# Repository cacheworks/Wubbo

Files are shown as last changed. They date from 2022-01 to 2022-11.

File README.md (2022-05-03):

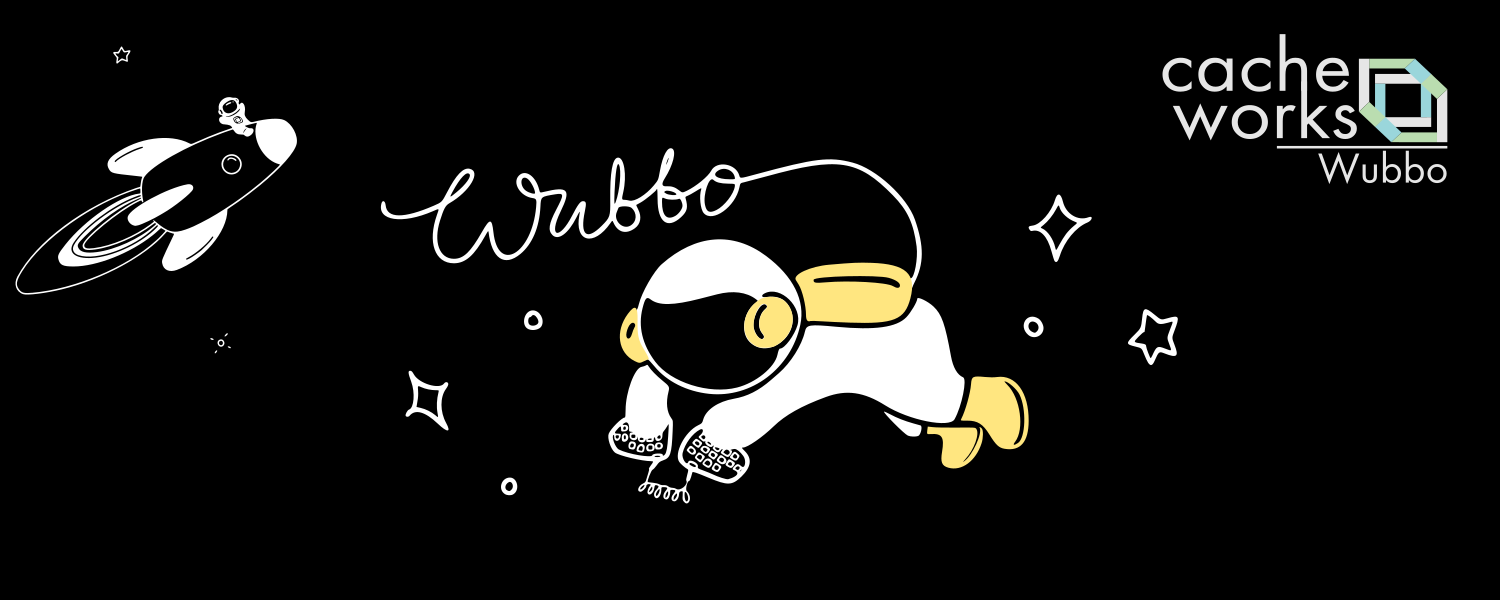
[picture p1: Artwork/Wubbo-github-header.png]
Wubbo header

A wireless 34 key keyboard with the top pinky keys moved to the 6th column.

### [Interactive Bill of materials](https://cacheworks.github.io/Wubbo/)
### [Example ZMK config repo](https://github.com/mveerd/wubbo-zmk-config)

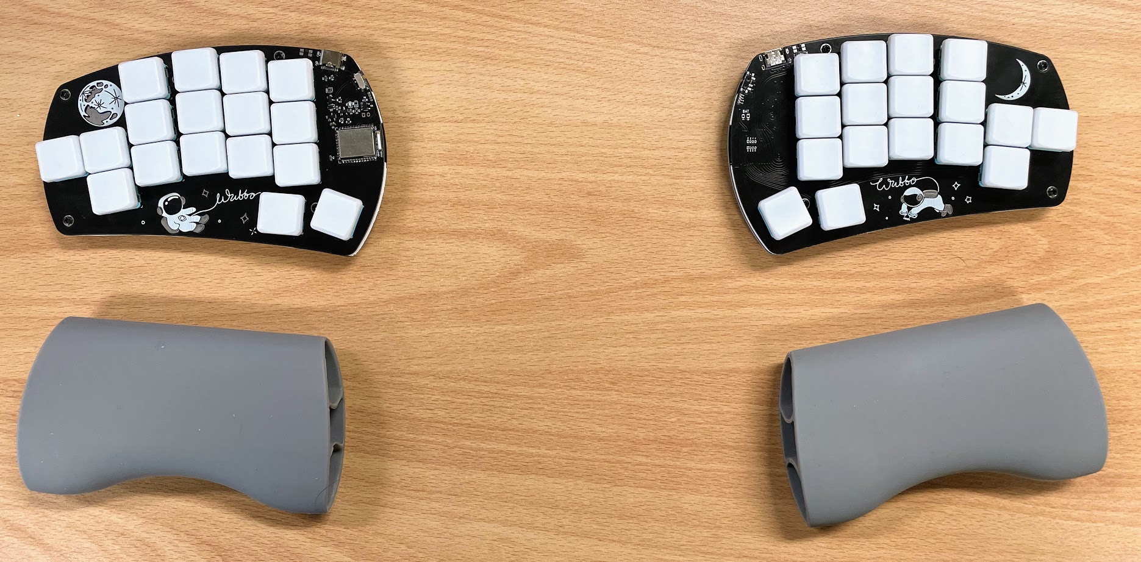
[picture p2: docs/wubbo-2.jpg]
Wubbo

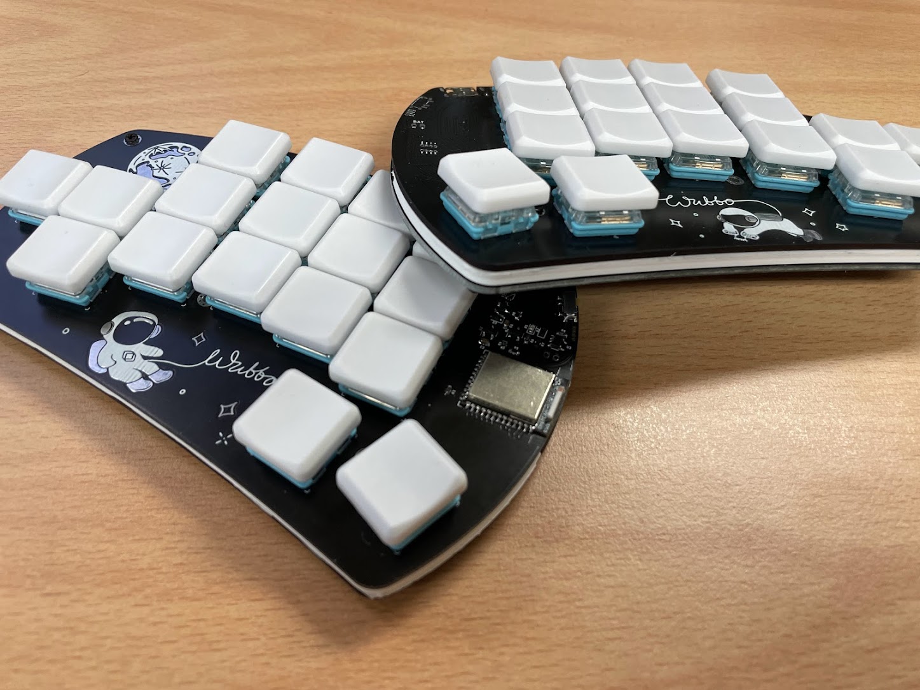
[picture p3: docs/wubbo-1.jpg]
Wubbo


---
__Why move the top pinky keys to the side?__  

 Moving my pinky to the side instead of upwards feels more natural and limits the movement and rotation of my hands on the board.  
This 'pinky cluster' is inspired by boards like [balbuzard](https://github.com/brow/balbuzard) and [osprette](https://github.com/smores56/osprette)

__Who did the silkscreen art?__  
  
All credits for the handdrawn art go to Perce at [madebyperce.com](https://madebyperce.com/)  🙇

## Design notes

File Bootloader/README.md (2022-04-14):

As defined in https://github.com/cacheworks/Adafruit_nRF52_Bootloader/tree/Wubbo/src/boards/wubbo

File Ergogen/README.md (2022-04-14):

This Ergogen config was only used for initial key / component placement and edge cut shape, further changes have been made in KiCad.

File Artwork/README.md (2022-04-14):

Full credits for all the hand-drawn art go to Perce [madebyperce.com](https://madebyperce.com/)  🙇

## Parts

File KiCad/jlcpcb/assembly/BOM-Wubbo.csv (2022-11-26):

Comment | Designator | Footprint | LCSC
SW_SPDT | SW_POW1 | SW_SPDT_PCM12 | C128955
1uF | C1,C2 | C_0603_1608Metric | C15849
4.7n | C3 | C_0805_2012Metric | C1744
AO3407 | Q1,Q2 | SOT-23 | C181093
D_Schottky | D3 | D_SOD-323 | C191023
1K | R6,R7 | R_0603_1608Metric | C21190
1M | R10 | R_0603_1608Metric | C22935
2M | R5,R9 | R_0603_1608Metric | C22976
5.1K | R1,R2 | R_0603_1608Metric | C23186
100K | R3 | R_0603_1608Metric | C25803
10K | R8 | R_0603_1608Metric | C25804
USBLC6-2P6 | ESD1 | SOT-666 | C2827693
LTC4054ES5-4.2 | U3 | TSOT-23-5 | C32574
806/820k | R4 | R_0603_1608Metric | C53198
XC6206P LDO | U2 | SOT-23 | C5446

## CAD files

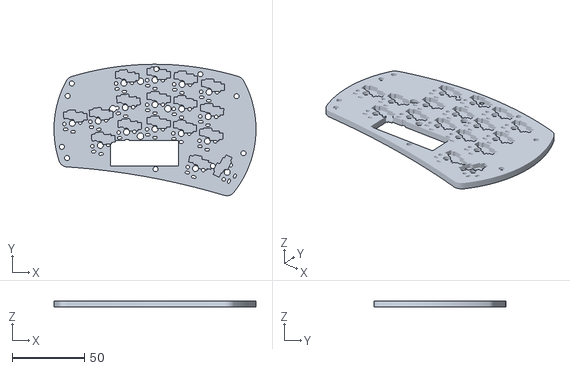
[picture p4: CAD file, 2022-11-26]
3D Print/wubmeat_v1 (1).stl
140.0 x 91.2 x 4.00

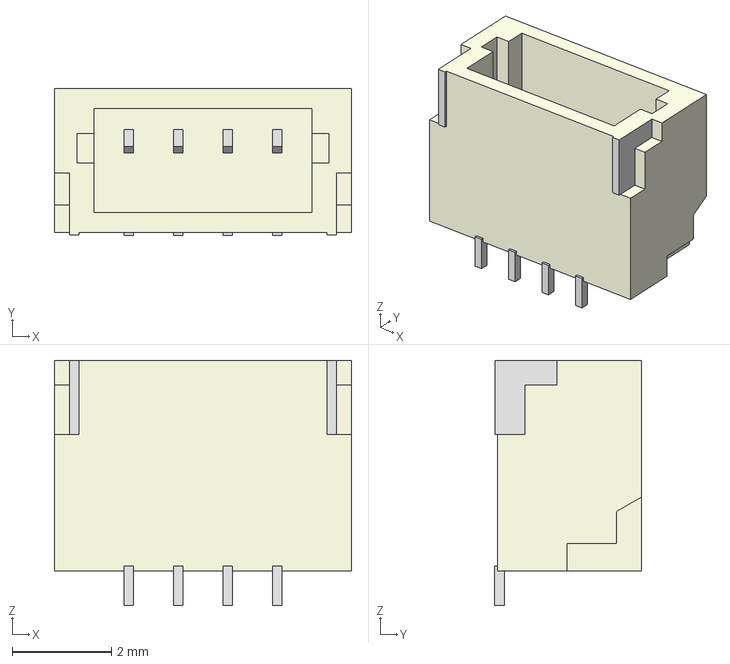
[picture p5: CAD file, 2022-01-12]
KiCad/3d/CON_SM04B-SRSS-TB.step
6.00 x 2.96 x 4.95 mm

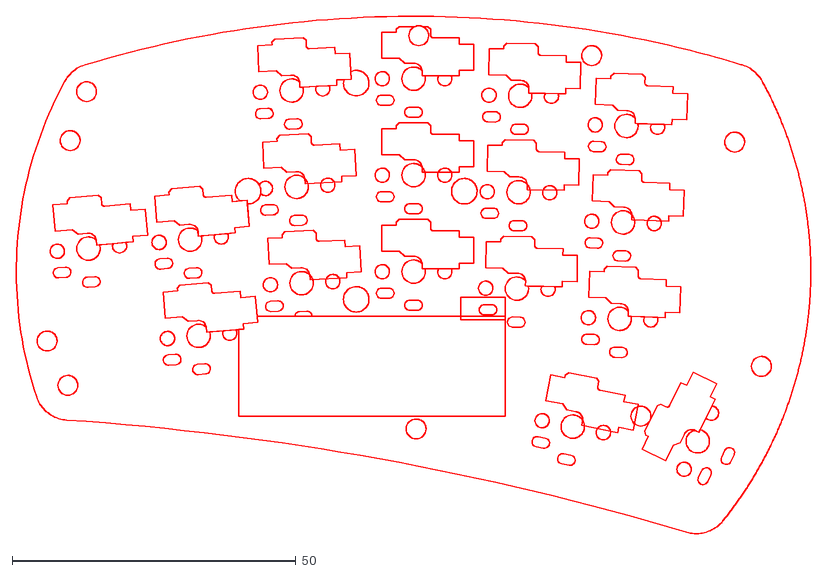
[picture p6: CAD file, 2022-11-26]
KiCad/svg/back/back.dxf
140.0 x 91.2

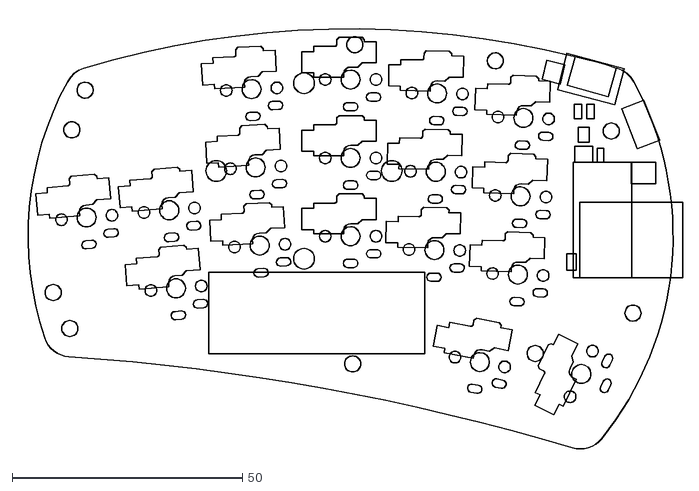
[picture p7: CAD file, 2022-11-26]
KiCad/svg/front/front.dxf
144.6 x 94.4

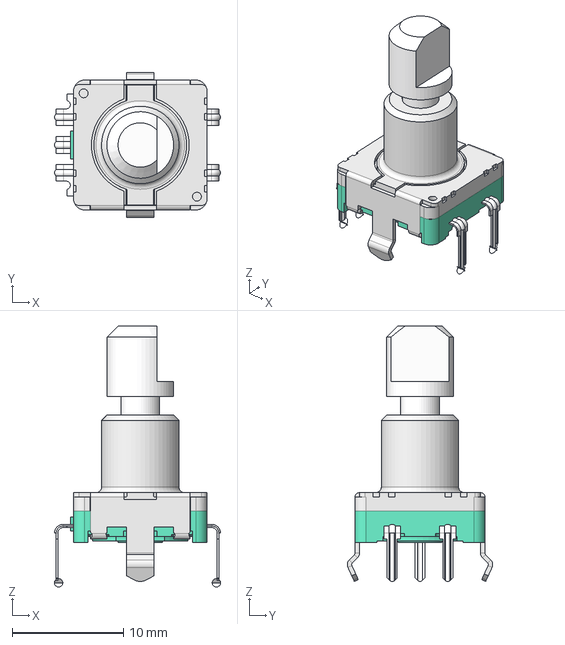
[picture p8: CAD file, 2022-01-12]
KiCad/3d/ROT_EC11N.step
14.9 x 13.1 x 23.5 mm

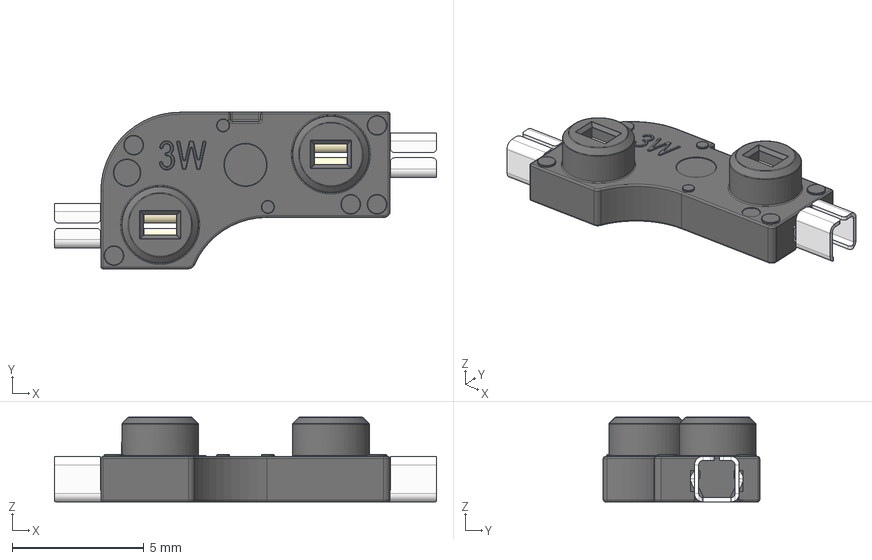
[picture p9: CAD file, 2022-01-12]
KiCad/3d/SW_Hotswap_Kailh.stp
14.5 x 5.95 x 3.22 mm

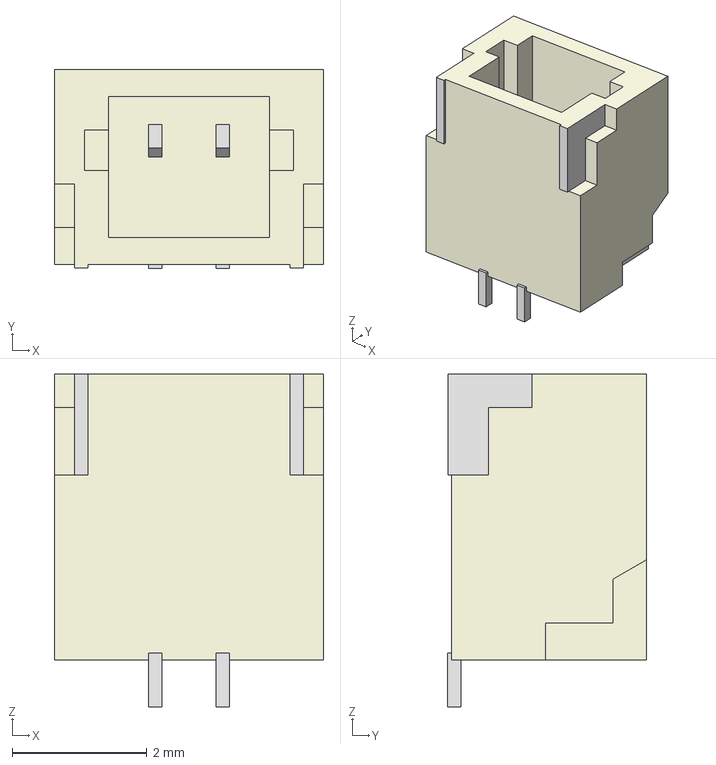
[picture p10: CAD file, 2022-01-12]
KiCad/3d/CON_SM02B-SRSS-TB.step
4.00 x 2.96 x 4.95 mm

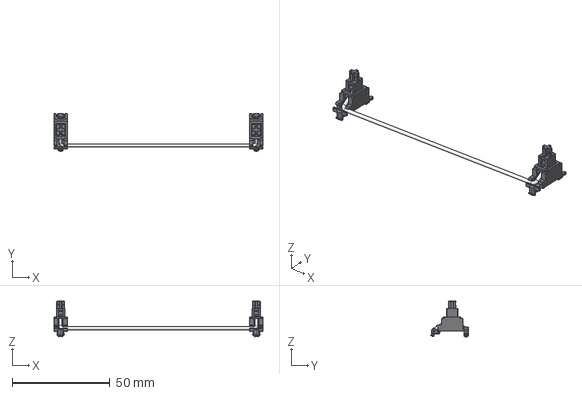
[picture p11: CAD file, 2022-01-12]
KiCad/3d/Stabilizer_Cherry_MX_6_25u.stp
106.8 x 19.2 x 18.3 mm

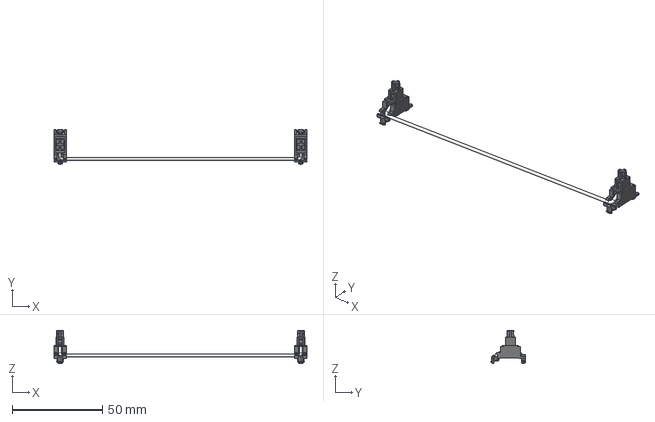
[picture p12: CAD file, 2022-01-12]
KiCad/3d/Stabilizer_Cherry_MX_8u.stp
140.1 x 19.2 x 18.3 mm

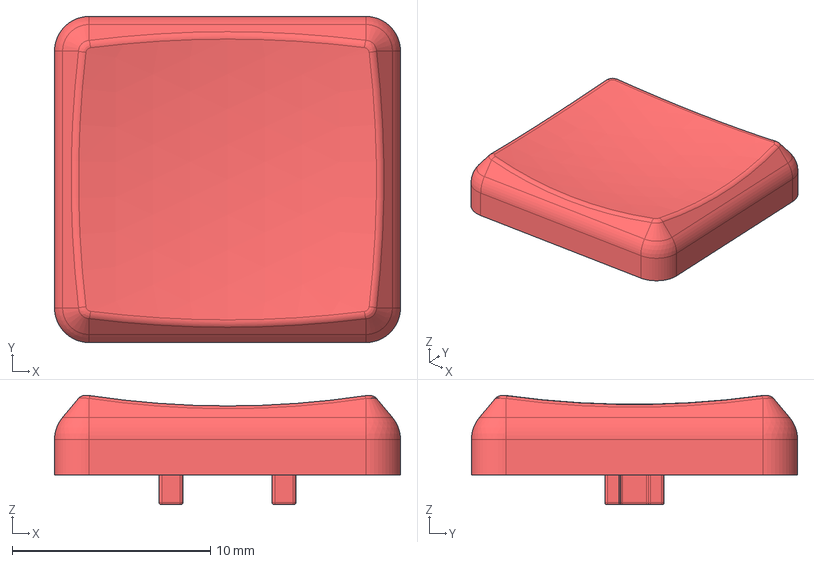
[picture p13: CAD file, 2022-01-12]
KiCad/3d/MBK_Keycap_-_1u.step
17.4 x 16.4 x 5.52 mm

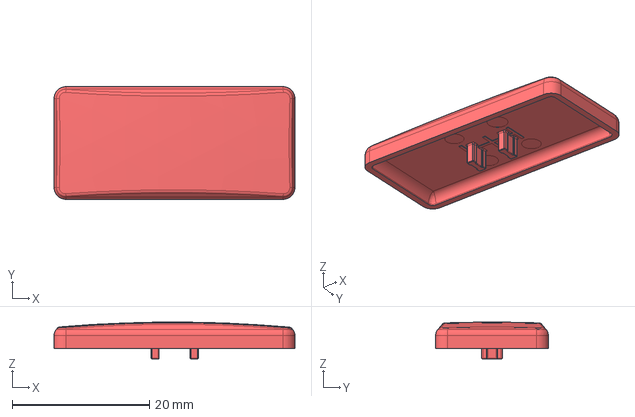
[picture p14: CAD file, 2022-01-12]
KiCad/3d/MBK_Keycap_-_2u.step
35.2 x 16.4 x 5.38 mm

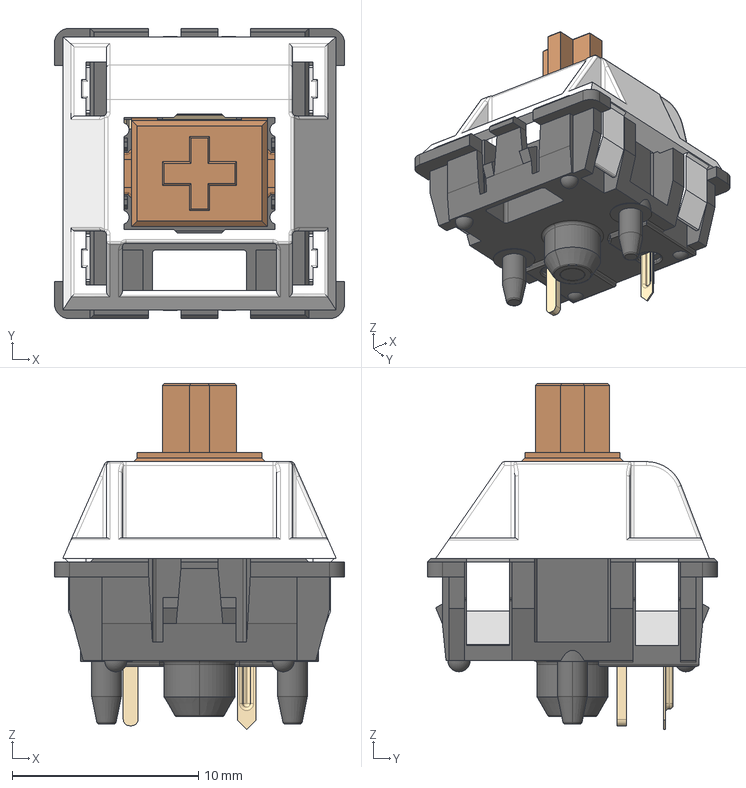
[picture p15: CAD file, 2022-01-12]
KiCad/3d/SW_Cherry_MX_PCB.stp
15.6 x 15.6 x 18.6 mm

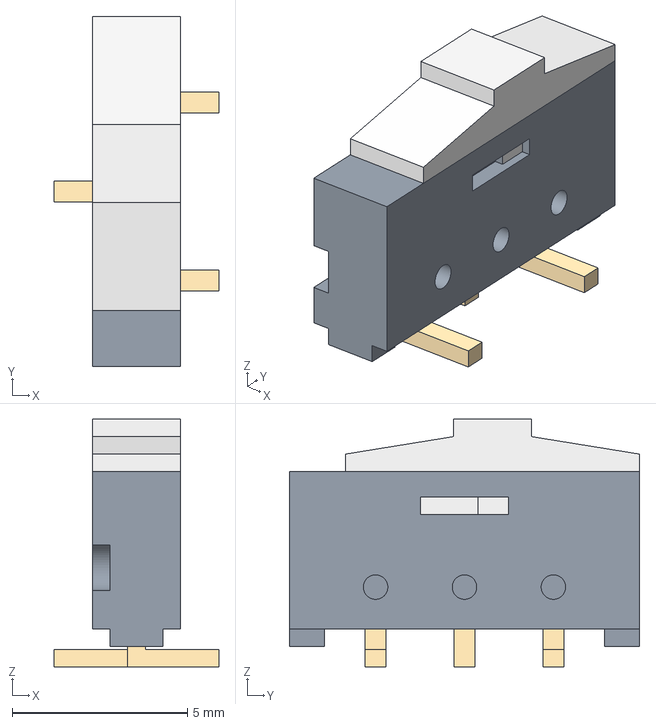
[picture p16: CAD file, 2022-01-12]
KiCad/3d/Switch_ESP3020.step
4.70 x 10.0 x 7.08 mm

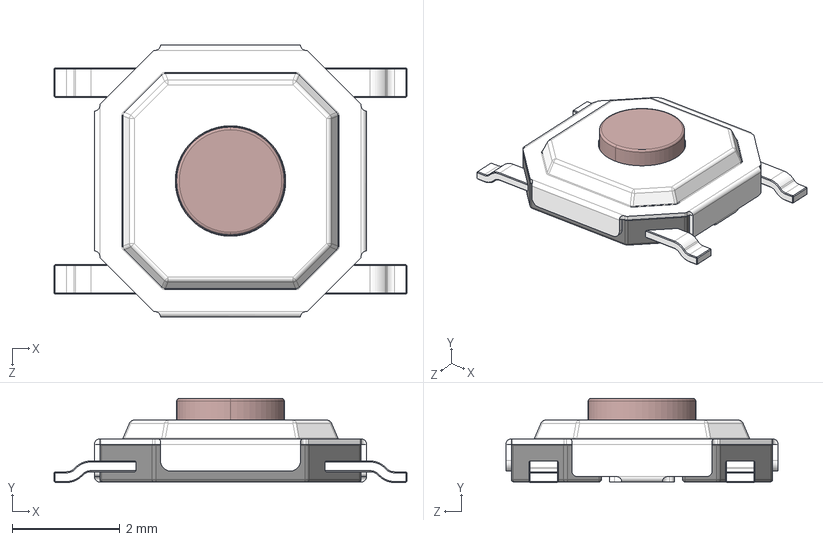
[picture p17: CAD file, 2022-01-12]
KiCad/3d/Switch_SKQG.step
6.55 x 1.56 x 5.05 mm
bottom part_ﾄｬﾈﾏｨｨ_
bottom pin_ﾄｬﾈﾏｨｨ_
top shield_ﾄｬﾈﾏｨｨ_
copper button_ﾄｬﾈﾏｨｨ_
shrapnel_默认è_

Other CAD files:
3D Print/frontmeat_v4.stl
KiCad/3d/HRO TYPE-C-31-M-12.step
KiCad/3d/USB-C-C168688.step
KiCad/3d/PG1350-socket.STEP
3D Print/wubmeat-back.f3d
3D Print/wubmeat-front.f3d
KiCad/3d/CON_Kailh_HS.step
KiCad/3d/CON_SM05B-SRSS-TB.step
KiCad/3d/CON_SM06B-SRSS-TB.step
KiCad/3d/CON_SM08B-SRSS-TB.step
KiCad/3d/CON_TYPE-C-31-M-12.step
KiCad/3d/Fuse_1206.step
KiCad/3d/LED_SK6812MINI-E.step
KiCad/3d/LED_WS2812B-MINI.step
KiCad/3d/MBK_1u.step
KiCad/3d/MBK_Keycap_-_1.5u.step
KiCad/3d/MBK_Keycap_-_1u_Homing.step
KiCad/3d/ROT_EC11E.step
KiCad/3d/SW_Cherry_MX_Plate.stp
KiCad/3d/SW_Kailh_Choc_V1.stp
KiCad/3d/Stabilizer_Cherry_MX_2u.stp
KiCad/3d/Stabilizer_Cherry_MX_3u.stp
KiCad/3d/Stabilizer_Cherry_MX_6u.stp
KiCad/3d/Stabilizer_Cherry_MX_7u.stp

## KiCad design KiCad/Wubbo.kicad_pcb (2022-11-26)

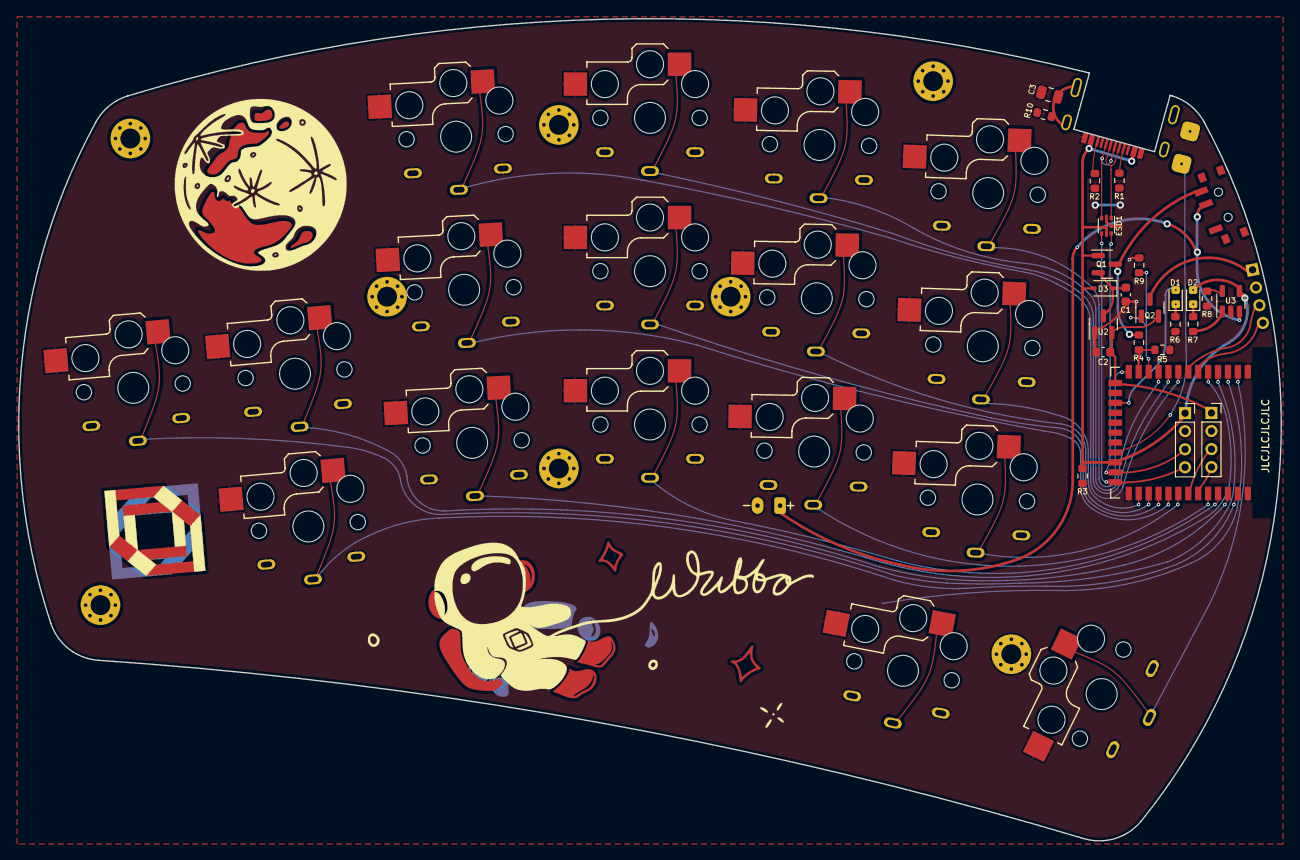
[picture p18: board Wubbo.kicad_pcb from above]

Board: 2 copper layers, 140.0 x 91.2 mm, 53 parts (1 on the bottom side), 43 nets.

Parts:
C1, C2: 1uF; C_0603_1608Metric
C3: 4.7n; C_0805_2012Metric
D1: Blue LED; LED_0603_1608Metric_shinethrough
D2: Red LED; LED_0603_1608Metric
D3: D_Schottky; D_SOD-323
ESD1: USBLC6-2P6; SOT-666
GR1, GR2: 9b7f651c-c6a4-4f53-b457-ec411c8fc700
GR3: frontright-2
GR4: frontleft-2
GR5: frontright-1
GR6: frontleft-1
J1: USB_C_Receptacle; USB-C-12-Pin-MidMount
J2: SWD; PinSocket_1x04_P2.00mm_Vertical
J3: USB; PinSocket_1x04_P2.00mm_Vertical
J4: JST-BATT; JST_PH_S2B-PH-K_1x02_P2.00mm_Horizontal
J5: USB; PinHeader_1x04_P2.00mm_Vertical
Q1, Q2: AO3407; SOT-23
R1, R2: 5.1K; R_0603_1608Metric
R3: 100K; R_0603_1608Metric
R4: 806/820k; R_0603_1608Metric
R5, R9: 2M; R_0603_1608Metric
R6, R7: 1K; R_0603_1608Metric
R8: 10K; R_0603_1608Metric
R10: 1M; R_0603_1608Metric
R_TACT1: SW_Push; 3-4-2_micro_tact_switch
SW1, SW2, SW3, SW4, SW5, SW6, SW7, SW8, SW9, SW10, SW11, SW12, SW13, SW14, SW15, SW16, SW17: Choc; combined-choc-reversible
SW_POW1: SW_SPDT; SW_SPDT_PCM12
TENT1: Tenting Puck; Tenting_Puck
U1: nRF52840_holyiot_18010
U2: XC6206P LDO; SOT-23
U3: LTC4054ES5-4.2; TSOT-23-5

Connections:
+3V3: C2.1, J2.1, Q2.2 (S), U1.14 (VDD_nRF), U2.2 (VO)
+BATT: J4.1, SW_POW1.2 (B), U3.3 (BAT)
/BAT+_SWITCHED: Q1.3 (D), R4.1, SW_POW1.3 (C)
/Net-(U3-PROG): R8.2, U3.5 (PROG)
/V-IN: C1.1, D3.1 (K), Q1.2 (S), U2.3 (VI)
BLUE_LED: D1.2 (A), U1.16 (P1.09)
D+: ESD1.4 (I/O2), J3.4, U1.24 (D+)
D-: ESD1.6 (I/O1), J3.3, U1.23 (D-)
EXT_VCC: J5.1, Q2.3 (D)
Earth: C3.2, J1.S1 (SHIELD), R10.2
GND: C1.2, C2.2, C3.1, ESD1.2 (GND), J1.A1 (GND), J2.2, J3.2, J4.2, J5.2, R1.2, R2.2, R3.2, R5.2, R6.2, R8.1, R9.2, R10.1, R_TACT1.2, SW1.2, SW2.2, SW3.2, SW4.2, SW5.2, SW6.2, SW7.2, SW8.2, SW9.2, SW10.2, SW11.2, SW12.2, SW13.2, SW14.2, SW15.2, SW16.2, SW17.2, U1.1 (GND), U1.25 (GND), U1.37 (GND), U2.1 (GND), U3.2 (GND)
unnamed: D1.1 (K), R6.1
unnamed: D2.1 (K), R7.1
unnamed: J1.A5 (CC1), R1.1
unnamed: J1.B5 (CC2), R2.1
unnamed: R7.2, U3.1 (~CHRG)
P0.02: J5.3, U1.7 (P0.02)
P0.03: J5.4, U1.6 (P0.03)
RESET: R_TACT1.1, U1.21 (P0.18/RESET)
SW1: SW1.1, U1.4 (P1.13)
SW2: SW2.1, U1.8 (P0.28)
SW3: SW3.1, U1.9 (P0.29)
SW4: SW4.1, U1.10 (P0.30)
SW5: SW5.1, U1.13 (P0.05)
SW6: SW6.1, U1.35 (P0.09)
SW7: SW7.1, U1.29 (P1.01)
SW8: SW8.1, U1.28 (P1.03)
SW9: SW9.1, U1.27 (P1.00)
SW10: SW10.1, U1.26 (P0.22)
SW11: SW11.1, U1.36 (P0.10)
SW12: SW12.1, U1.5 (P1.15)
SW13: SW13.1, U1.34 (P1.06)
SW14: SW14.1, U1.33 (P1.04)
SW15: SW15.1, U1.30 (P1.02)
SW16: SW16.1, U1.3 (P1.10)
SW17: SW17.1, U1.2 (P1.11)
SWDCLK: J2.3, U1.31 (SWDCLK)
SWDIO: J2.4, U1.32 (SWDIO)
USBD+: ESD1.3 (I/O2), J1.A6 (D+), J1.B6 (D+)
USBD-: ESD1.1 (I/O1), J1.A7 (D-), J1.B7 (D-)
VBUS: D2.2 (A), D3.2 (A), ESD1.5 (VBUS), J1.A4 (VBUS), J3.1, Q1.1 (G), R3.1, U1.22 (VBUS), U3.4 (VCC)
VCC_CONTROL: Q2.1 (G), R9.1, U1.11 (P0.31)
VSENSE: R4.2, R5.1, U1.12 (P0.04)

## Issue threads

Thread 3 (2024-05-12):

Symbol library missing?

iosonofabio, 2024-05-12:
hi there and thanks for sharing your awesome design! I really like it!

I'd like to open and edit the design in kicad, but it does not seem to be able to find the schematic library for the keyboard parts. Could it be that it's missing from the repo?

Thank you for your time!

MvEerd, 2024-05-13:
Hey, thanks for your interest, much appreciated!

I've just tried downloading the repo as zip and opened Wubbo.kicad_pro (in KiCad 8.0) and was able to open Wubbo.kicad_pcb and Wubbo.kicad_sch with seemingly no errors

Where are you getting the error and what does it say exactly? If it points to a specific library I'm happy to see if I have it locally andadd it to the repo for you!

iosonofabio, 2024-05-14:
Thank you for the quick reply!

I must be doing something wrong. The PCB does load but when I click on "Update PCB from Schematic" it throws a bunch of errors like this:

```
Cannot update SW15 (footprint 'kiboard_cache:PG13500-reversible' not found).
```

(17 errors in total, one per key I guess).

I tried to import the footprint from the same folder but still get the error.

If you could give me a tip in the right direction I'd really appreciate, apologies beforehand if it's a beginner mistake.

MvEerd, 2024-05-14:
No worries!

Unchecking 'Replace footprints with those specified in the schematic' in the Update PCB from Schematic would get rid of the 17 errors you are seeing for the keys.
I thought there should be no need to Update the PCB from Schematic since when I open the PCB and the schematic side by side it already highlights the components I click in the schematic in the PCB view so it already seems up to date.

It would be good to add the footprint to the repository though so I just re-extracted it from the PCB and uploaded the kiboard_cache library here [kiboard_cache.pretty.zip](https://github.com/cacheworks/Wubbo/files/15303986/kiboard_cache.pretty.zip)

By importing this library into your footprint editor, relaunching the PCB editor and trying to Update the PCB from Schematic again it should get rid of the error.
Another way is to import the footprint to any of your own libraries and double clicking the switch symbols in the schematic, there you can browse for the footprint you imported locally.

I will get this added to the repository or upload a library as a separate repo, thanks for the heads up!
Feel free to let me know if you're still getting stuck on this.

iosonofabio, 2024-05-14:
Thank you, wow that was fast!

i got it to work both ways ;-)

now when I actually press `Update PCB` it comes up with 24 errors:

```
...
Error: U1 pad 44 not found in nRF52840_holyiot_18010.
Error: U1 pad 45 not found in nRF52840_holyiot_18010.
Error: J1 pad B9 not found in USB-C-12-Pin-MidMount.
Error: J1 pad B4 not found in USB-C-12-Pin-MidMount.
Error: J1 pad A9 not found in USB-C-12-Pin-MidMount.
Error: J1 pad B12 not found in USB-C-12-Pin-MidMount.
Error: J1 pad B1 not found in USB-C-12-Pin-MidMount.
Error: J1 pad A12 not found in USB-C-12-Pin-MidMount.
```

Not sure if that matters, it seems like perhaps the holyiot symbol is incomplete even though the PCB looks good

MvEerd, 2024-05-14:
Going back through this I realize I actually made some changes like supporting hotswap were made without fully updating the schematic so I would be wary of the automatic updates KiCad does and look through them to see what it changed. I have not had the need to use this functionality

The Holyiot footprint comes from ebastler's library here https://github.com/ebastler/kicad-keyboard-parts.pretty
The UCB-C-12-Pin-MidMount comes from Keebio's parts library https://github.com/keebio/Keebio-Parts.pretty/blob/master/USB-C-12-Pin-MidMount.kicad_mod
I think importing those libraries would solve your other errors.

I will look into proper ways to include these footprints and libraries in the repository itself so it's all self-contained

iosonofabio, 2024-05-14:
Thank you! It's already super useful as it is, but of course appreciate any improvements.

I'm playing around with the concept of a third thumb button which is why I'm bothering you. I got some homework to do now :-P

iosonofabio, 2024-05-15:
hey @MvEerd, apologies for the barrage, I wonder if you soldered everything yourself or got a partial assembly from JLCPCB?

Looks like the holyiot, two LEDs, reset button, and J2-5 (plus obviously the switches) are not included in the CLP, and perhaps the schottky D3 and the USB port J1?

MvEerd, 2024-05-16:
@iosonofabio  No problem!
I never got around to build guide but see how that would have been useful here 🙃

v0.1 and v0.2 were hand soldered, v0.3 is indeed only _partially_ assembled by JLCPCB

The HolyIot module (U1) was not available from JLCPCB at the time I ordered, as well as the mid-mount USB C port I wanted to use (J1)

I had a bunch of reset buttons laying around and wanted those on alternating sides for each half so opted to use those instead of picking an alternative from JLCPCB (R_TACT1). The same goes for the power switch (SW_SPDT)
The LEDs were manually soldered because - besides also wanting these on alternating sides for each half - I mount those _upside down_ from the back side of the pads, the middle part of that footprint is clear FR4.

The schottky diode (D3) is included in the assembly BOM and POS https://github.com/cacheworks/Wubbo/blob/main/KiCad/jlcpcb/assembly/POS-Wubbo.csv

I'm not sure what J2-5 is referring to, I fail to see those on the BOM (?)

iosonofabio, 2024-05-21:
Thank you @MvEerd , really appreciated! The Js must be jumpers I guess. I'm iterating a few designs at the moment, I think we can close this if you want.

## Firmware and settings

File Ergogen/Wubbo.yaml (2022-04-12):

units:
  # Parameters
  row_spacing: 1cy

  pinky_rotation: 5 # degrees rotation relative to zone rotation
  pinky_stagger: 0 # mm, relative to previous column
  pinky_spread: 1cx # mm, relative to previous column

  ring_rotation: 3
  ring_stagger: 0.45cy
  ring_spread: 1.05cx

  middle_rotation: 0
  middle_stagger: 1
  middle_spread: 1.1cx

  index_rotation: -1
  index_stagger: -3
  index_spread: 1cx

  inner_rotation: -2
  inner_stagger: -5
  inner_spread: 1cx

  usb_cutout_x:  47
  usb_cutout_y: -1.27
  usb_cutout_r: -15.5

  # Constants
  choc_cap_x: 17.5
  choc_cap_y: 16.5

  choc_plate_thickness: 1.2
  mx_plate_thickness: 1.5

  # demo.dxf multiplies key.width/height by this value
  visual_x: 1
  visual_y: 1

points:
  rotate: 0
  mirror:
  key: # each key across all zones will have these properties
    bind: 5
    width: choc_cap_x
    height: choc_cap_y
    tags:
      1u: true
    footprints: # These footprints will be added for each of the points
      choc_hotswap:
        type: choc
        nets:
          to: =key_net
          from: GND
        params:
          reverse: false
          hotswap: true
          # Don't show a model for this since 'choc' already loads the model
          model: false
          keycaps: false
      choc:
        type: choc
        anchor: 
          rotate: 180
        nets:
          to: =key_net
          from: GND
        params:
          keycaps: true
          reverse: false
      # A trace to connect each hotswap socket with a pin hole (do a 4mm fillet on these in KiCad)
      trace:
        type: trace
        params:
          side: B
          points: [
            [0, 6],
            [6, 6],
            [9, 4],
            [9, -4]
          ]
  zones:
    alphas:
      rows:
        bottom.padding: row_spacing
        home.padding: row_spacing
        top.padding: row_spacing
      columns:
        pinkycluster:
          rotate: pinky_rotation
          rows:
            bottom.skip: true
            home.key_net: P106
            top.skip: true
        pinky:
          rotate: pinky_rotation - pinky_rotation
          stagger: pinky_stagger
          spread: pinky_spread
          rows:
            bottom.key_net: P104
            home.key_net: P102
            top:
              key_net: test
              footprints:
                choc: $unset
                trace: $unset
                choc_hotswap: $unset
                encoder:
                  type: rotary
                  nets:
                    from: =key_net
                    to: GND
                    A: TODO3
                    B: TODO4
                    C: GND
        ring:
          rotate: ring_rotation - pinky_rotation
          stagger: ring_stagger
          spread: ring_spread
          rows:
            bottom.key_net: P101
            home.key_net: P103
            top.key_net: P100
        middle:
          rotate: middle_rotation - ring_rotation
          stagger: middle_stagger
          spread: middle_spread
          rows:
            bottom.key_net: P022
            home.key_net: P029
            top.key_net: P030
        index:
          rotate: index_rotation - middle_rotation
          stagger: index_stagger
          spread: index_spread
          rows:
            bottom.key_net: P031
            home.key_net: P004
            top.key_net: P005
        inner:
          rotate: inner_rotation - index_rotation
          stagger: inner_stagger
          spread: inner_spread
          rows:
            bottom.key_net: P007
            home.key_net: P109
            top.key_net: P012
    thumbkeys:
      anchor:
        ref: alphas_index_bottom
        shift: [ 0.5cx, -1cy - 2]
      columns:
        near:
          rotate: -10
          stagger: -5
          origin: [ 0, -0.5cy ]
          key.key_net: P009
        home:
          spread: 19
          stagger: 0.25cy # Move up by 0.25cy so a 1.5cy keycap lines up with the bottom
          rotate: -15 # -25 degrees cumulative
          origin: [-0.5choc_cap_y, -0.75choc_cap_x] # Pivot at the lower left corner of a 1.5u choc key
          key:
            height: choc_cap_x
            width: 1.5choc_cap_y
            rotate: 90
            tags:
              15u: true
              1u: false
            key_net: P010
            #footprints.choc.anchor.rotate: 270
            #footprints.choc_hotswap.anchor.rotate: 90
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

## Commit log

2022-01-12 WIP PCB
    [CON_Kailh_HS.step, CON_SM02B-SRSS-TB.step, CON_SM04B-SRSS-TB.step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]
2022-04-12 remove rotary encoder from schematic
    [Wubbo.kicad_sch]
